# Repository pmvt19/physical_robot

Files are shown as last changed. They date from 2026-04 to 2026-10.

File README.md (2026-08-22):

# SunoBot 

<!-- ![SunoBotLogo](./assets/SunoBotLogo.png) -->

<p align="center">
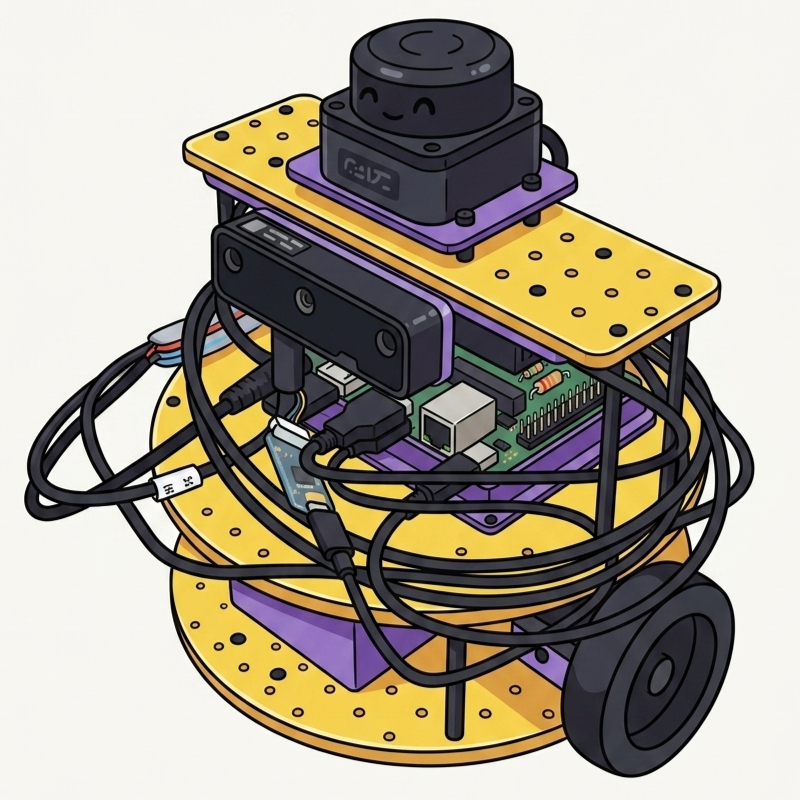
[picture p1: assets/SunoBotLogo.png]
SunoBotLogo


<p align="center">
SunoBot is an open-source autonomous mobile robot platform meant to explore computer vision, motion planning, and robot design.

## Capabilities:

<p float="center">
  
  
  
</p>

# Monitoring UI - RoboMonitor Pro

The RoboMonitor Pro Monitoring UI allows users to monitor the current readings of all on-board sensors on the SunoBot.

The list of natively monitored sensors:
- Lidar
- RGB Camera
- Depth Camera
- Accelerometer
- Gyroscope

The monitoring UI also includes additional information about the real-time motor positions and velocities.

Example:
<p align="center">
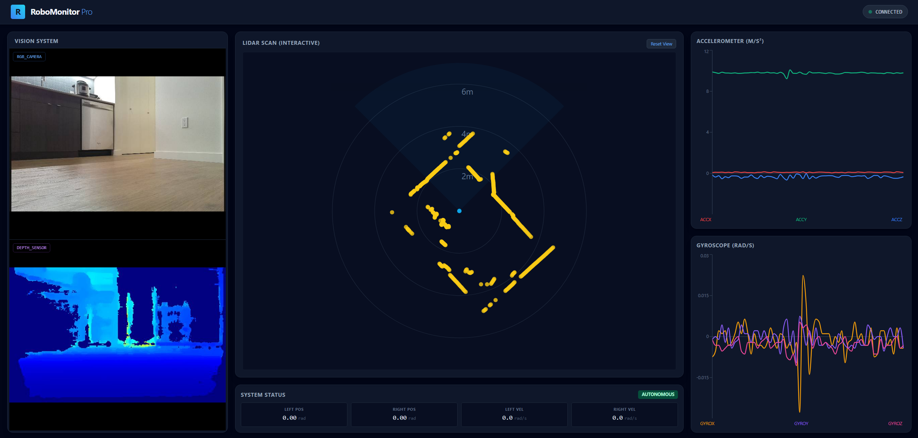
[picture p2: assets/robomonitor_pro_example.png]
RoboMonitorPro

<!-- Insert Example UI Image -->

# Equipped Sensors

## Lidar - RPLidar C1

<p align="center">
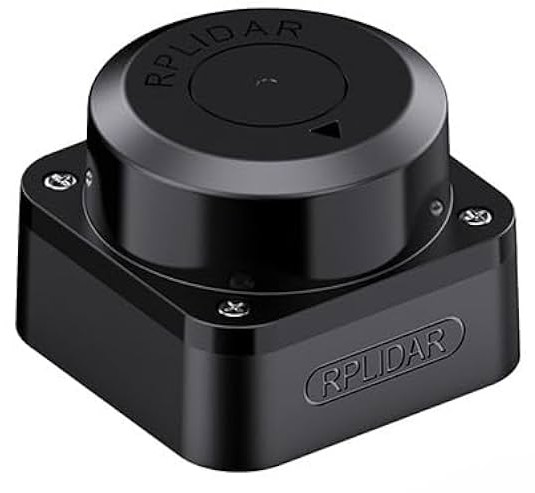
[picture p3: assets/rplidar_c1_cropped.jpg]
RPLidar C1


<!-- Example Readings -->
<!-- Maybe add gif of lidar readings? -->

### Specifications
- Max Range: 12 meters
- Accuracy: 30 mm
- Angular Resolution: 0.72 degrees

## Stereo Depth Camera - Oak-D Lite

<p align="center">
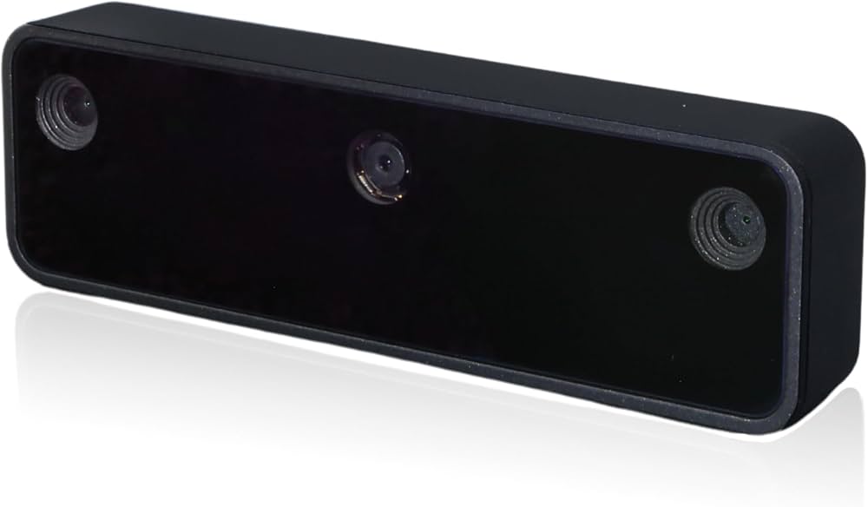
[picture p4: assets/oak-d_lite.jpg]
Oak-D Lite


### Specifications
- Photo Resolution: 13 MP (Auto-Focus Variant)
- Video Resolution: 1080p
- IMU: 6-axis sensor with accelerometer and gyroscope
- Onboard Compute to run computer vision algorithms and models

<!-- Example Readings -->

<!-- Front on Vision, Depth Camera, 3D Point Cloud -->

# Motors - Dynamixel WL430-XL250-T
<p align="center">
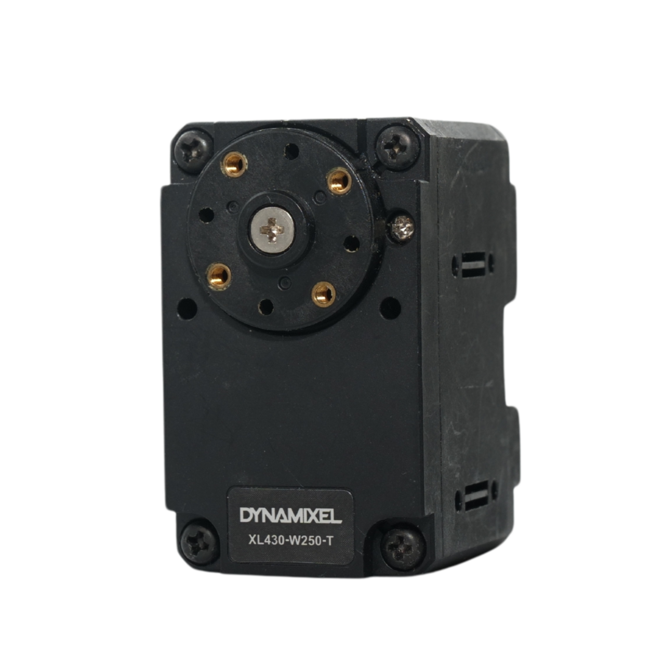
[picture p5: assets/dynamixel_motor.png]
Dynamixel Motors


This motor includes built-in encoders for accurate positioning. 

### Specifications
- Estimated Torque: 0.28 Nm 
- Resolution: 4096 Steps

# Code Installation

Requires Python >=3.12.9

```sh
pip install suno-bot
```

For systems with an Nvidia GPU, you can use the following command to ensure you install torch with cuda to accelerate inference when running local models.

```sh
pip install suno-bot[cuda]
```

# Build List
| Part | Quantity | Unit Price (USD) | Link |
| --- | --- | --- | --- |
| **Compute** | 
| Nvidia Jetson Nano Orin | 1 | $250 | [Amazon](https://a.co/d/08duLBSw) |
| 128 GB Micro SD Card | 1 | $34 | [Amazon](https://a.co/d/0giFn1uy) |
| **Sensors** |
| RPLidar C1 | 1 | $69 | [Amazon](https://a.co/d/01sqCkox) |
| Luxonis OAK-D Camera | 1 | $170 | [Luxonis](https://shop.luxonis.com/products/oak-d-lite-1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) |
| **Motors & Accessories** |
| Dynamixel XL-250 | 2 | $27.50 | [Robotis](https://www.robotis.us/dynamixel-xl430-w250-t/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) |
| U2D2 | 1 | $36.92 | [Robotis](https://www.robotis.us/u2d2/?srsltid=AfmBOooSLo45Nv1YYB132Rkxfk1DpJbxzMnHwRaMWvsoDXhAL2AbefDP) |
| U2D2 Powerboard | 1 | $21.85 | [Robotis](https://www.robotis.us/u2d2-power-hub-board-set/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) | 
| **Power & Accessories** |
| KBT 12V Battery | 1 | $30 | [Amazon](https://a.co/d/07AhwwMU) |
| 8x AA Battery Holder | 1 | $9 | [Amazon](https://a.co/d/021ZlgrT) |
| 20x AA Batteries | 1 | $10 | [Amazon](https://a.co/d/07lIH3iI) |
| USB C to USB A Cable | 1 | $7 | [Amazon](https://a.co/d/0gSawx84) |
| **Assembly Hardware** |
| Turtle Bot 3 Wheel and Tire Kit (2 Pack) | 1 | $10.81 | [Robotis](https://www.robotis.us/tb3-wheel-tire-set-isw-01-2ea/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) |
| Turtle Bot 3 Casters | 2 | $4.03 | [Robotis](https://www.robotis.us/tb3-ball-caster-a01-1ea/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) |
| Screw Pack | 1 | $9 | [Amazon](https://a.co/d/002Dz5YJ) |
| Standoffs | 1 | $10 | [Amazon](https://a.co/d/06RelOfa) |
| **Total** | --- | **$730.64** | --- |

# Chassis & Brackets - 3D Printed Parts
| Part | Quantity | CAD File |
| --- | --- | --- |
| Base Board | 2 | [Link](./CAD/Robot%20Base%20Plate.stl) |
| Motor Mounts | 2 | [Link](./CAD/430T%20Motor%20Mounts.stl) |
| Sensor Mounting Bracket Riser | 1 | [Link](./CAD/Lidar%20Mounting%20Plate%20Wide.stl) |
| Jetson Mount | 1 | [Link](./CAD/Jetson%20Mount.stl) |
| Jetson Securing Bracket | 1 | [Link](./CAD/Jetson%20Securing%20Bracket.stl) |
| Camera Mounting Bracket | 1 | [Link](./CAD/Camera%20Mounting%20Bracket.stl) |
| Camera Mounting Bracket Spacer | 1 | [Link](./CAD/OAK-D%20Lite%20Camera%20Mount.stl) |
| Lidar Mounting Bracket | 1 | [Link](./CAD/Lidar%20Mounting%20Plate.stl) |
| KBT Battery Holder | 1 | [Link](./CAD/KBT%20Battery%20Holder.stl) |
| AA Battery Holder | 1 | [Link](./CAD/8%20AA%20Battery%20Holder%20Horizontal.stl) |

### Printer
Any 3D printer large enough should work to print all of these parts. For reference, I printed these parts using a Prusa MK4S printer with PLA and got fairly decent results.

# Assembly Instructions
Please follow this tutorial for instructions on how to assemble the SunoBot.

# Software Architecture

SunoBot supports three different connection types: Simulated, Server-Client, and Physical (Local).

## Simulated
The simluated robot provides a limited set of functionality primarily used for simple testing.

In simulated mode, the robot only has access to a simulated lidar sensor that requires a prebuilt map to read data from. The only functionalities that work in this case are: SLAM, Global Localization, and Semantic Navigation (given the Semantic Map is already built).

The major limitation here is that you cannot *build* semantic maps since we have not implemented a way to simulate the Stereo Depth camera. However, you can localize, plan, and navigate in a prebuilt semantic map as these actions only require the use of the lidar.

## Running Server-Client
### Software Architecture
<p align="center">
Dynamixel Motors

This version of the robot runs a gRPC Server on the Robot's compute and a client on the off-board computer. The gRPC Server manages reading the live sensor data and acuating the motors based on RPC calls from the client.

This architecture allows the client use the robot client as if it were running locally on the robot instead of connected via a gRPC server-client relationship.

All other functionalities of the robot such as mapping, motion planning, navigation, etc. happens on the client side. This allows the robot to operate with much higher compute power of the off-board machine.

## Running Locally
### Software Architecture
<p align="center">
Dynamixel Motors

This version of the robot has the robot client object read sensor data directly from the Redis server's database. It provides the same functionality as running the robot via server and client, but does not require an internet connection to support the network-based gRPC calls.

It is also possible to run a completely local version of the robot by running both the server and client on the robot. However, this method is not recommended due to the circular network calls that would be made to send data from the robot back to the robot. This implementation does not have zero-copy data transfer. But, in theory, it would work.

# Getting Started Guide

## Setup the config

## Running Locally
*Not fully supported yet*

On the robot computer:
```sh
# Start publishing sensor data
sh physical_robot/scripts/start_sensor_suite.sh
```

## Running via RPC Server-Client

### Running the sensor suite
On the robot computer:
```sh
# Start publishing sensor data
sh physical_robot/scripts/start_sensor_suite.sh

# Start the RPC Server on the robot
python physical_robot/robot/robot_server.py
```

### Using the Monitoring UI

On the Client:
```sh
# Start the Publishing Monitoring Data to Websocket
python physical_robot/ui/ui_server.py

# Run the Javascript App
sh physical_robot/shell_scripts/run_ui.sh
```

# Future Plans
ROS Integration

<!-- # Technology Stack

<p float="center">
  <img src="https://cdn.jsdelivr.net/gh/devicons/devicon/icons/python/python-original.svg" width="22%" style="border-radius: 15px;"/>
  <img src="https://cdn.jsdelivr.net/gh/devicons/devicon/icons/numpy/numpy-original.svg" width="22%" style="border-radius: 15px;"/>
  <img src="https://upload.wikimedia.org/wikipedia/commons/b/b2/SCIPY_2.svg" width=22%" style="border-radius: 15px;"/>
  <img src="https://upload.wikimedia.org/wikipedia/commons/0/05/Scikit_learn_logo_small.svg" width="32%" style="border-radius: 15px;"/>
  <img src="https://huggingface.co/front/assets/huggingface_logo-noborder.svg" width="22%" style="border-radius: 15px;"/>
  <img src="https://www.luxonis.com/assets/marketing/brand/luxonis_logo_symbol.png" width="22%" style="border-radius: 15px;"/>
  <img src="https://www.gstatic.com/lamda/images/gemini_sparkle_v002_d4735304ff6292a690345.svg" width="22%" style="border-radius: 15px;"/>
  <img src="https://cdn.jsdelivr.net/gh/devicons/devicon/icons/opencv/opencv-original.svg" width="22%" style="border-radius: 15px;"/>
  <img src="https://cdn.jsdelivr.net/gh/devicons/devicon/icons/pytorch/pytorch-original.svg" width="22%" style="border-radius: 15px;"/>
  <img src="https://plugins.jetbrains.com/files/14004/1074279/icon/default.png" width="22%" style="border-radius: 15px;"/>
  <img src="https://cdn.jsdelivr.net/gh/devicons/devicon/icons/matplotlib/matplotlib-original.svg" width="22%" style="border-radius: 15px;"/>
  <img src="https://images.icon-icons.com/2415/PNG/512/redis_original_wordmark_logo_icon_146369.png" width="22%" style="border-radius: 15px;"/>
</p> -->

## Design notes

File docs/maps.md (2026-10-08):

# SunoBot Maps

## Map

Raw Map Dimensionality: `(X, Y)`

### World and Grid Coordinates

### Update Map and Localize

### Expandability
As this map is built without knowning the full extent of the environment, it is possible the environment is larger that the initial size of the map. If an update step tries to update a map cell that is outside the bounds of the current size of the map, the map will autoexpand in the X and Y dimensions to at least encompass the cell the new lidar readings were trying to update.

### Inflate Obstacles

A single point on the lidar reading only updates the map obstalces for a single grid cell, which is geometrically where the obstacle is. This is generally fine if our goal was to only map the room geometrically, however motion planning in this map could be quite risky since grid cells close to obstacles are still marked as completely free.

The Inflate Obstacles function expands the occupied cells in the map to create a buffer between the free cells and occupied cells.

<!-- Example Image of Inflated Obstacle Cells -->

## Advanced Map

Raw Map Dimensionality: `(X, Y, 2)`

The Advanced Map stores the count of times each cell was recorded as empty or occupied. Using these counter, we compute a probability that the cell is occupied.

This is a more robust solution as a single reading does not permanently define a cell as occupied. A cell is only considered occupied if it strictly has more occupied readings than unoccupied readings. This means the cell must have a probability of being occupied of more than 50%.
 
$`\text{Occupancy Probablity}_{i,j}`$ = $`\frac{\text{Occupied}_{i,j} + 1}{\text{Occupied}_{i,j} + \text{Unoccupied}_{i,j} + 2}`$ 

### Benefits
This offers greater reliability for objects that may have moved through the scene while mapping, such as a human or pet walking, as these entities will eventually be cleared from the map. 

Additionally, this helps to smooth out noisy lidar readings. Suppose a wall is directly forward and exactly 5 meters away. The lidar may read this distance as 4.7 meters which leaves us with a 30 centimeter error. In the previous map implementation, we would mark the cell corresponding to 4.7 meters forward as occupied and move on, never to be updated or corrected. With the implementation in the advanced map, we will increment the occupied counter of the cell 4.7 meters forward. Since there is not really an object there, as we get more accurate readings from the lidar, it will hopefully show the wall being closer to 5 meters away and we will increment the unoccupied counter for the cell 4.7 meters forward, eventually converging to a occupied probability of 0%.

### Computing Frontiers

Using this method we can compute the boundaries of where the robot has explored.
<!-- Example Image of Frontiers -->

## Semantic Map

Raw Map Dimensionality: Depends on base geometric map (Recommended to use AdvancedMap)

Semantic Map Dimensionality: `(X, Y, 2)`

The Semantic Map adds an additional layer to store information about the semantic information of each obstacle. Semanic information includes what room the obstacle is associated with and what the obstacle is. For example, if the robot registers an oven next to it, it would label the semantic information as (Room: kitchen) & (Object: Oven).

The internal implementation of this map uses either a Map or AdvancedMap to store the geometric representation of the map. It is recommended to use the `AdvancedMap` class for the geometric component of the map, but it is possible to use the `Map` class if required. Just note that the `AdvancedMap` class features will not be available if using the standard `Map` class.

<!-- Example of Raw Semantic Information (Unfloodfilled) -->

### FloodFill Semantics

<!-- Example of Raw Semantic Information (Unfloodfilled) and FloodFilled Map-->

Semantic information is not mapped for every single grid cell in the map. To assign a semantic label to each open grid cell, the semantic map *flood fills* the unlabeled grid cells. For each unlabeled unoccupied grid cell, flood filling assigns the same label as closest labeled grid cell. 

Closest can be measured in 2 ways: BFS or Nearest Neighbors. BFS flood filling respects known obstacles in the map, meaning it finds the shortest collision free path between a labeled and an unlabeled cell. Nearest Neighbor flood filling labels an unlabeled cell with the label of the closest labeled cell using euclidean distance. This means that if a wall is labeled a 'kitchen', then it may label the other side of the wall kitchen as well if that side is open and unlabeled.

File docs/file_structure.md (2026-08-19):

```
physical_robot/
├── physical_robot/
    ├──generated/
        ├──robot_data_pb2_grpc.py...

    ├──saves/
        ├──scenes/
            ├──tmp/
                ├──map/
                ├──map_imgs/
                ├──planner_data/
    ├──maps/
        ├──basic_map.py
        ├──map.py
        ├──advanced_map.py
        ├──abstract_map.py
        ├──semantic_map.py

    ├──shell_scripts/
        ├──proto_gen.sh
        ├──start_lidar_process.sh
        ├──start_camera_process.sh
        ├──start_sensor_suite.sh

    ├──debugging/
        ├──debug.py
        ├──debug_lidar_angles.py

    ├──monitoring/
        ├──viz_camera.py
        ├──viz_robot_lidar.py
        ├──viz_imu.py
        ├──viz_point_cloud.py

    ├──utils/
        ├──utils.py
        ├──test_utils.py

    ├──hardware/
        ├──robot_interface.py (robot_motor_interface.py)
        ├──dxl_controller.py

    ├──sensors/
        ├──physical/
            ├──run_camera.py
            ├──run_camera_elite.py
            ├──run_lidar.py
        ├──simulated/
            ├──simualte_lidar.py
    
    ├──processes/
        ├──run_interactive_robot.py (run_slam.py)
        ├──run_localization_robot.py
        ├──run_robot.py
        ├──run_localize_and_plan.py
        ├──run_nlp_mp_robot.py (TODO)

    ├──machine_learning/ (TODO)
        ├──image_processing/
            ├──image_segmentator.py
        ├──language_processing/
            ├──language_processor.py

    ├──robot/
        ├──robot.py
        ├──robot_space.py
        ├──robot_server.py
        ├──robot_controller.py

    ├──algorithms/
        ├──icp.py
        ├──particle_filter.py

    ├──config/
        ├──config.py

    ├──protos/
        ├──robot_data.proto

    ├──tests/
        ├──test_sensors/
            ├──test_lidar.py
            ├──test_camera.py
            ├──test_imu.py
        ├──test_processes/
            ├──test_particle_filter.py
            ├──test_slam.py??

    ├──tests/
        ├──sensors/
            ├──test_lidar.py
            ├──test_camera.py
            ├──test_imu.py
        ├──processes/
            ├──test_particle_filter.py
            ├──test_slam.py??
            ├──test_vlm_client.py
        ├──visual/
            ├──tbd.py??
        ├──computational/
            ├──test_robot_controller.py
            ├──test_geometry_utils.py
            ├──etc...

    # Potential Future Planning
    ├──mcp/
        ├──server.py
        ├──tools.py
    
    ├──main.py??

Remaining files:
- icp.py
- particle_filter.py

Planned files:
- image_segmentator.py
- language_processor.py
- run_nlp_mp_robot.py
- start_sensor_suite.sh
- start_camera_process.sh
- semantic_map.py
- run_slam_semantic_mapping.py

Files to Rename:
- run_interactive_robot.py -> run_slam.py
- run_localization_robot.py -> run_global_localization.py
- run_localize_and_plan.py -> run_motion_planning.py??

- run_camera.py -> run_oakd_lite.py or run_oakd_camera.py

│   ├── components/
│   │   ├── Button.js
│   │   └── Header.js
│   ├── pages/
│   │   ├── HomePage.js
│   │   └── AboutPage.js
│   └── App.js
├── public/
│   ├── index.html
│   └── favicon.ico
├── package.json
└── README.md
```

## Installation

```sh
conda create --name <name> python=3.10.18

sh env_setup.sh
```

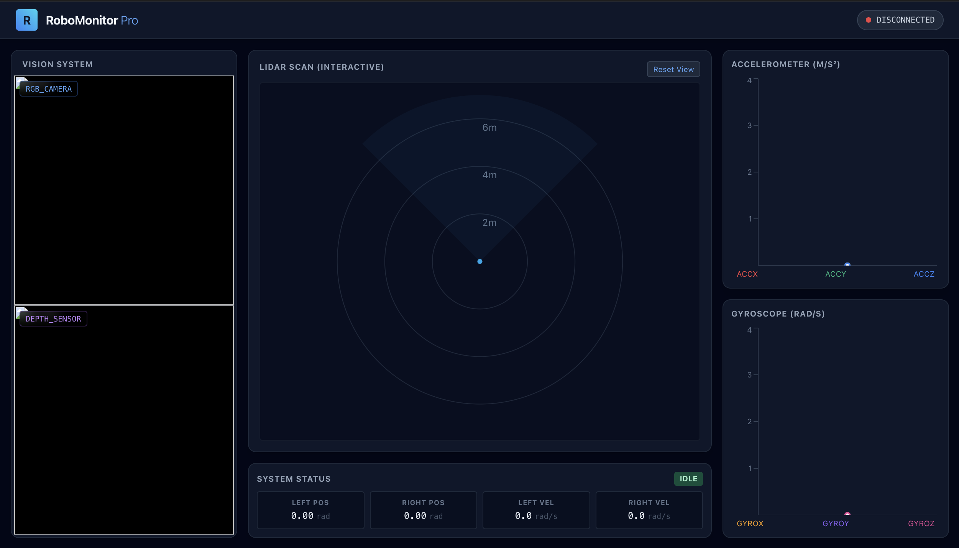
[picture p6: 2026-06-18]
assets/robomonitor_pro_blank.png

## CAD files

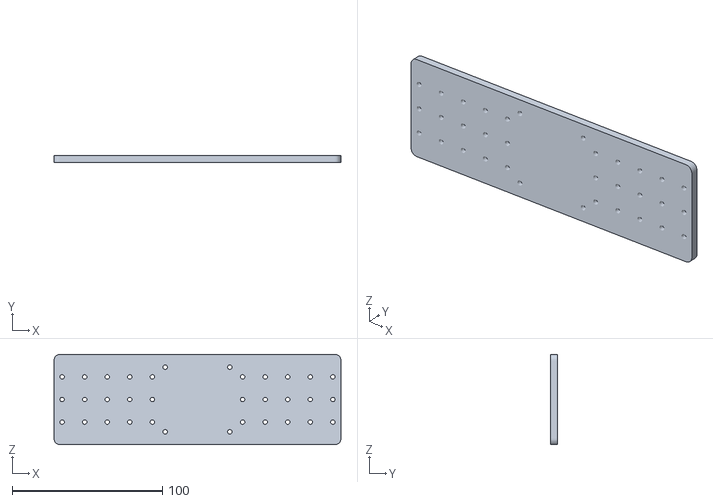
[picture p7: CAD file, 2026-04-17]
CAD/Lidar Mounting Plate Wide.stl
190.8 x 4.50 x 60.0

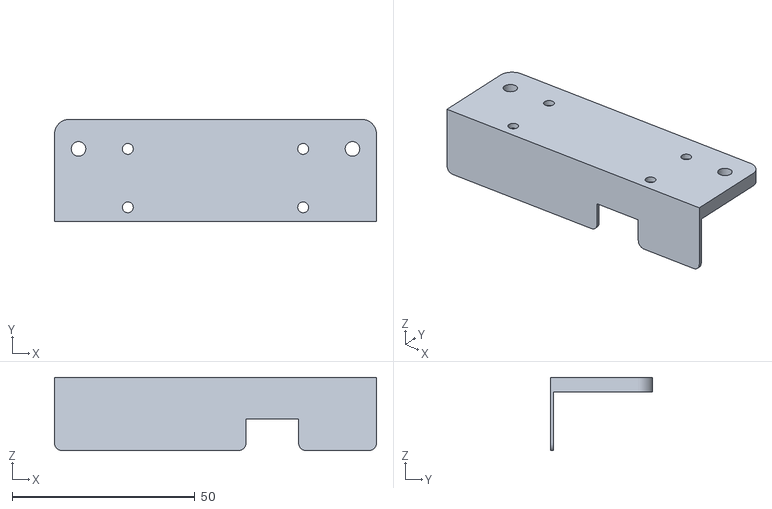
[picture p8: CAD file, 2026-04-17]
CAD/OAK-D Lite Camera Mount.stl
88.2 x 28.0 x 20.0

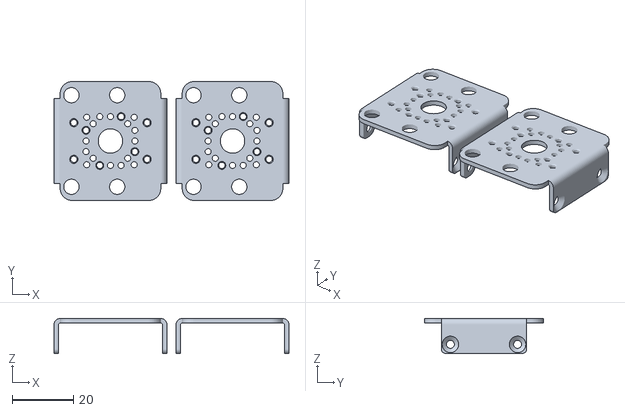
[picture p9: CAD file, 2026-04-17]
CAD/430T Motor Mounts.stl
77.0 x 39.0 x 11.5

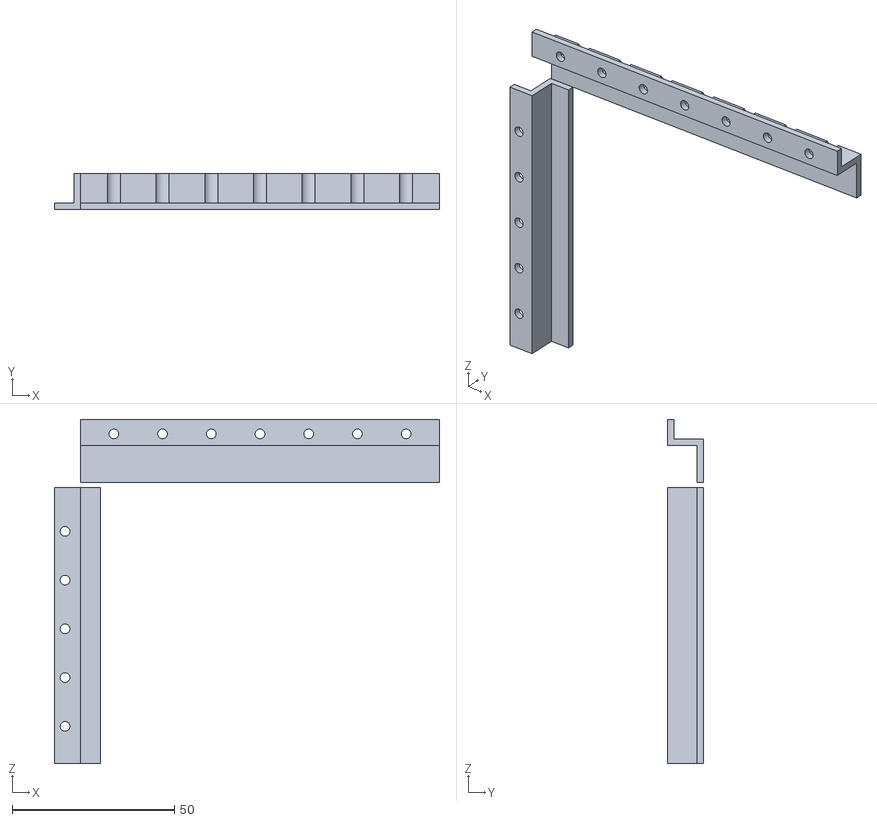
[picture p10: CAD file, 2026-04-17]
CAD/Jetson Securing Bracket.stl
118.5 x 11.0 x 106.0

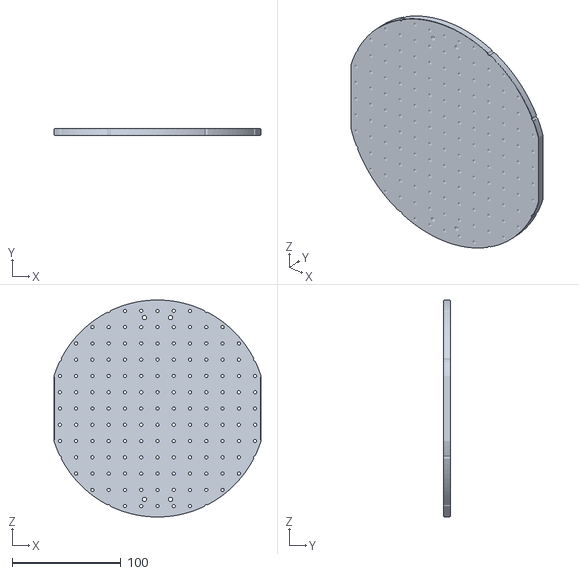
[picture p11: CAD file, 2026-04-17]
CAD/Robot Base Plate.stl
190.8 x 6.00 x 200.0

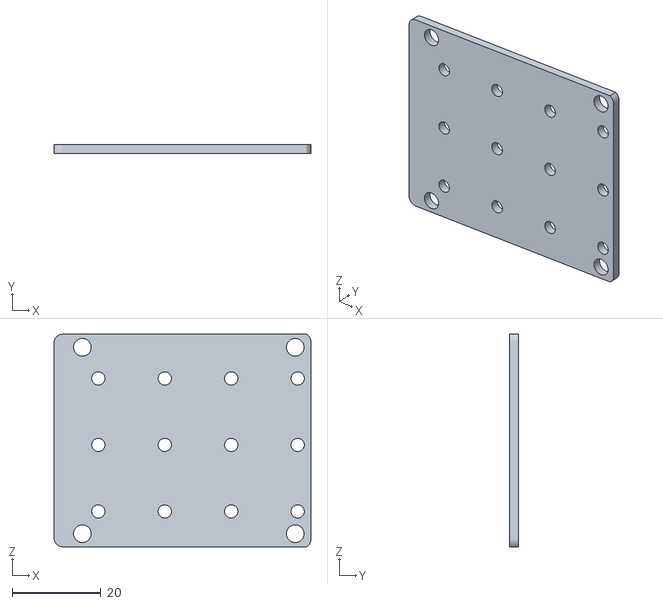
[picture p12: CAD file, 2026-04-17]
CAD/U2D2 Powerboard Mounting Bracket.stl
58.0 x 2.00 x 48.0

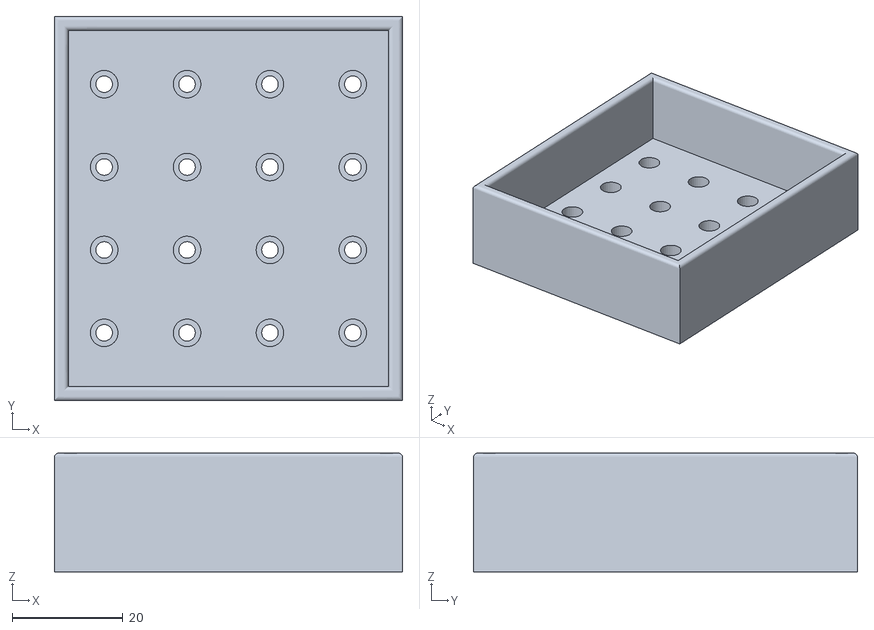
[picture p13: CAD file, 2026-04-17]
CAD/8 AA Battery Holder Horizontal.stl
63.0 x 69.5 x 21.5

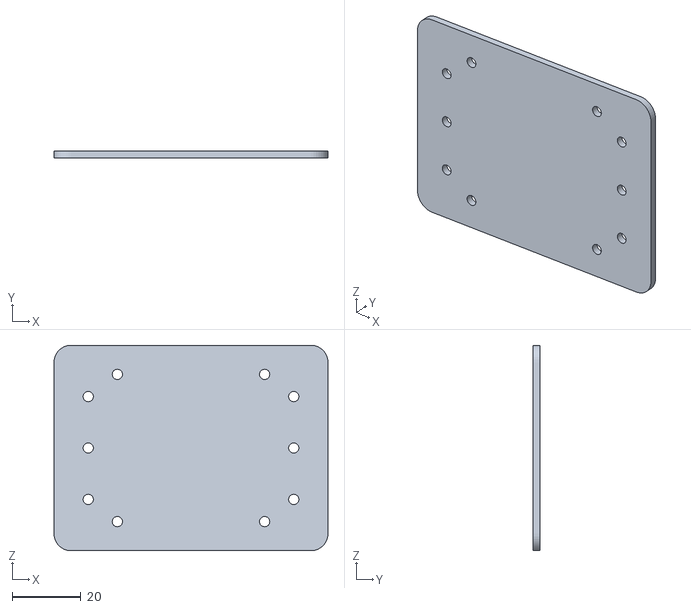
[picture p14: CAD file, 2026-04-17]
CAD/Lidar Mounting Plate.stl
80.0 x 2.00 x 60.0

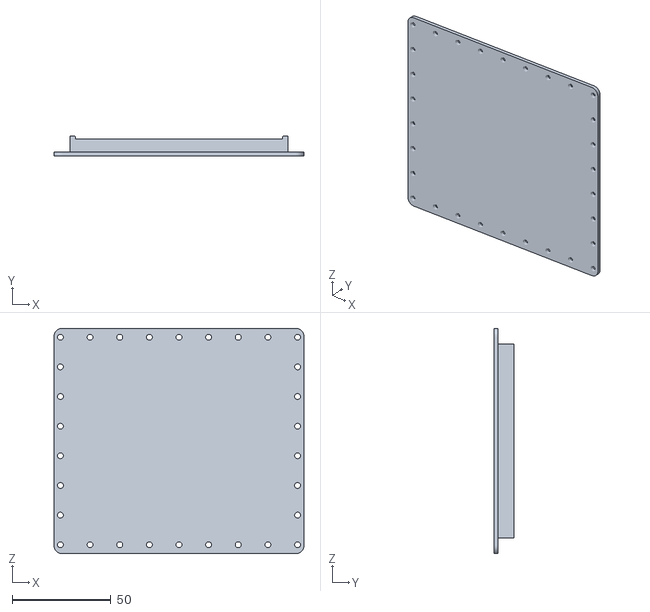
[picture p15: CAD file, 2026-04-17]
CAD/Jetson Mount.stl
126.5 x 10.0 x 114.0

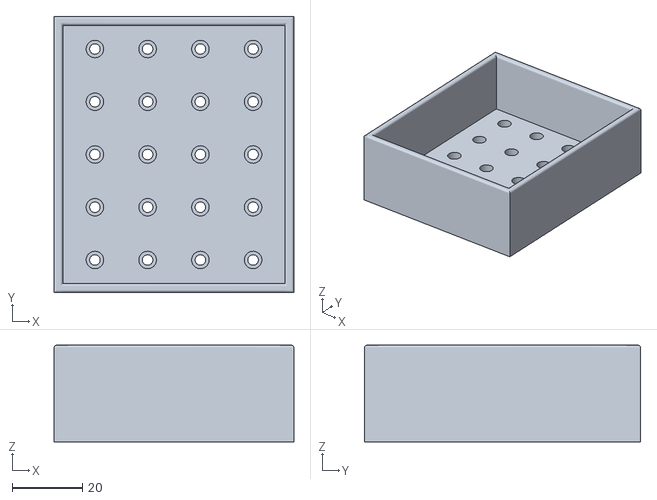
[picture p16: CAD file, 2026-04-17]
CAD/KBT Battery Holder.stl
68.2 x 78.5 x 27.5

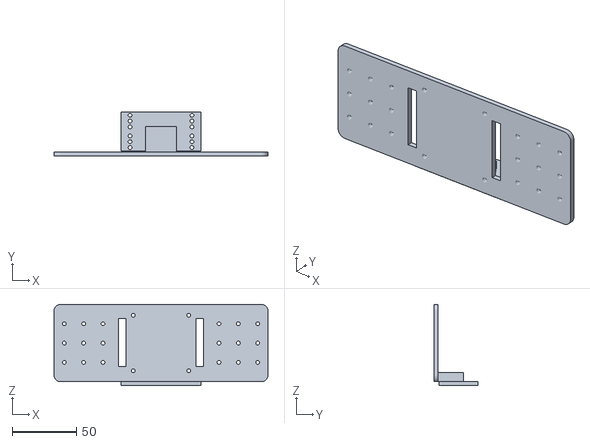
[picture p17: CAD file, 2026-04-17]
CAD/Camera Mounting Bracket.stl
166.0 x 34.0 x 63.0

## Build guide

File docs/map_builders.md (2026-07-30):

# MapBuilders

The `MapBuilder` classes provide an easy to use interface for building maps of an environment. The SunoBot code provides 3 variants of MapBuilders: `MapBuilder`, `AdvancedMapBuilder`, and `SemanticMapBuilder` classes. Intuitively, these variants build a `Map`, `AdvancedMap`, or `SemanticMap` respectively.

# MapBuilder Class

The `MapBuilder` class coordinates a robotic system and its LiDAR sensor data to construct, update, and track a spatial map over time. It maintains the robot's current state, trajectories, and handles map updates per time step.

## Table of Contents
- [Initialization](#initialization)
- [Methods](#methods)
- [Usage Example](#usage-example)

---

## Initialization

```python
def __init__(self, robot, map_resolution=10.0, manual_lidar_verification=False)
```

Initializes the map building coordinator.

### Parameters
| Parameter | Type | Default | Description |
| :--- | :--- | :--- | :--- |
| `robot` | `Robot` | *Required* | An instance of the `Robot` class providing movement and sensor interfaces. |
| `map_resolution` | `float` | `10.0` | The grid resolution scale for the generated map. Units in millimeters. |
| `manual_lidar_verification` | `bool` | `False` | If `True`, prompts manual user verification for every LiDAR reading. Mainly used for debugging purposes. |

### Internal State Attributes
* **`self.robot_state`** (`np.ndarray`): A 3-element array `[x, y, theta]` tracking the robot's current pose. Starts at `[0.0, 0.0, 0.0]`.
* **`self.map`** (`Map`): The underlying map object initialized with the given resolution.
* **`self.robot_trajectory`** (`list[np.ndarray]`): A history list recording the robot's state at every step.

---

## Methods

### `init()`
Performs the initial LiDAR scan to establish and initialize the map's baseline geometry.
* **Returns:** `None`

### `step(m)`
Executes a single iteration of the localization and mapping loop. It predicts the new state based on movement, reads the sensor, and refines the map.
* **Parameters:** `m`: Movement/Odometry data passed to the robot's state prediction model.
* **Returns:** `None`

### `get_map()`
* **Returns:** `Map` — The current state of the map object.

### `get_robot_state()`
* **Returns:** `np.ndarray` — The current `[x, y, theta]` pose of the robot.

### `get_robot_trajectory()`
* **Returns:** `list[np.ndarray]` — A chronological list of all historic robot states.

### `show()`
Renders a visual representation of the current map using `matplotlib`.
* **Returns:** `None`

---

## Usage Example

```python
from physical_robot.robot import Robot
from physical_robot.map_builder import MapBuilder

# 1. Setup the robot and builder
robot = Robot()
map_builder = MapBuilder(robot=robot, map_resolution=12.5)

# 2. Baseline the map
map_builder.init()

while True:
    # 3. Get Motion Commands from User
    motion_command = robot.request_motion_command_from_user()
    if motion_command[0] == '': # No Motion Command
        break

    # 4. Move the Robot
    m = robot.command_motion(motion_command)

    # 5. Step The Map Builder
    map_builder.step(m)

    # 6. Fetch results or visualize
    current_pose = map_builder.get_robot_state()
    print(f"Robot is at: {current_pose}")

    # 7. Visualize Current Map
    map_builder.show()

# 8. Save the Map
map_builder.get_map().save(map_save_dir="saves/maps")
```

## AdvancedMapBuilder

`AdvancedMapBuilder` inherits from `MapBuilder` and preserves the same high-level map-building workflow while using an `AdvancedMap` implementation for richer geometry and exploration features.

### Key differences from `MapBuilder`
- Inherits all public methods from `MapBuilder`: `init()`, `step(m)`, `get_map()`, `get_robot_state()`, `get_robot_trajectory()`, and `show()`.
- Replaces the base `Map` with `AdvancedMap` during initialization.
- Gains advanced map semantics such as probabilistic occupancy, obstacle inflation, and frontier candidate generation.
- Uses the same LiDAR-based scan initialization and update loop as `MapBuilder`.

### Initialization
```python
map_builder = AdvancedMapBuilder(robot=robot, map_resolution=12.5)
```
This constructs a map builder whose underlying map is an `AdvancedMap`.

### Behavior
- `init()` performs the initial LiDAR scan and initializes the advanced map.
- `step(m)` predicts the robot state, reads an updated LiDAR scan, runs ICP alignment, updates the `AdvancedMap`, and appends the new pose to the robot trajectory.
- `get_map()` returns the `AdvancedMap` instance, enabling access to advanced operations such as inflated occupancy and frontier detection.

### When to use
Use `AdvancedMapBuilder` when you need more than a simple occupancy map and want a map representation that supports:
- better alignment between scans and map geometry,
- probabilistic occupancy values,
- obstacle inflation for planning,
- frontier candidate extraction for exploration.

## SemanticMapBuilder
The `SemanticMapBuilder` extends `MapBuilder` to produce a `SemanticMap` that combines geometric mapping with semantic labels (rooms and objects).

### Purpose
The `SemanticMapBuilder` augments an occupancy/geometry map with semantic information derived from RGB images and point clouds. It is intended for use-cases where high-level scene understanding (room types, object labels) improves exploration, planning, or human-facing visualization.

### Key Features
- Builds a `SemanticMap` (backed by an `AdvancedMap`) that stores both geometry and semantic layers (e.g., `room`, `object`).
- Integrates LiDAR, RGB camera, and point-cloud data to localize, segment, and label the environment.
- Uses an image segmenter and a vision-language model (VLM) client to assign room labels and object semantics.

### Sensor & ML Dependencies
- LiDAR: used for geometry updates and scan-to-map alignment (via the same LiDAR-based flow as `MapBuilder`/`AdvancedMapBuilder`).
- RGB Camera: provides images for segmentation and room-label queries.
- Point Cloud: combined with image segmentation to label 3D points with semantic categories.
- Image segmentation: `physical_robot.models.segmentation.image_segmentation.ImageSegmenter` is used to produce pixel-level segments.
- Vision-Language Model (VLM): `physical_robot.models.vlm.vlm_client.VLMClient` is queried (with prompts such as `ASSIGN_ROOM_LABEL`) to produce a room-level label for the current view.

Files: see [physical_robot/map_builder/semantic_map_builder.py](physical_robot/map_builder/semantic_map_builder.py) for the implementation and references to:
- [physical_robot/maps/semantic_map.py](physical_robot/maps/semantic_map.py)
- [physical_robot/models/segmentation/image_segmentation.py](physical_robot/models/segmentation/image_segmentation.py)
- [physical_robot/models/vlm/vlm_client.py](physical_robot/models/vlm/vlm_client.py)

### Workflow (what `step(m)` does)
1. Update the internal robot state using the provided motion/odometry `m`.
2. Read an updated LiDAR scan (optionally with manual verification).
3. Capture an RGB image from the robot camera.
4. Read the point cloud snapshot.
5. Query the VLM with the RGB image and a prompt that lists known/invalid rooms to get a room label.
6. Run image segmentation on the RGB image to get pixel-level segments and labels.
7. Project/associate segmentation labels onto the point cloud and filter/format points for the semantic map.
8. Update the `SemanticMap` with both geometry (from LiDAR / point cloud) and semantics (room/object labels), and append the robot pose to the trajectory.

This workflow is implemented in `SemanticMapBuilder.step()` and tightly couples geometric updates with semantic inference so the map remains both spatially accurate and semantically meaningful.

### Visualization (`show()`)
`SemanticMapBuilder.show()` renders multiple panels using `matplotlib`:
- A geometric/occupancy view of the map.
- A semantic layer for `room` labels.
- A semantic layer for `object` labels.

### Initialization
```python
from physical_robot.robot import Robot
from physical_robot.map_builder import SemanticMapBuilder

robot = Robot()
builder = SemanticMapBuilder(robot=robot, map_resolution=10.0, manual_lidar_verification=False)
builder.init()
```

### When to use
- Use `SemanticMapBuilder` when downstream tasks (navigation, human-robot interaction, semantic exploration) require knowledge of room types or object categories beyond raw geometry.

### Notes and configuration
- The builder instantiates `ImageSegmenter` and `VLMClient` by default; these components may require model weights, credentials, or network access depending on your configured backends. Check their module-level docs for setup details.
- The `map_resolution` parameter controls the underlying `AdvancedMap` resolution; pick a resolution appropriate for your sensors and environment scale.
- For debugging or mapping quality control, enable `manual_lidar_verification` to pause for manual LiDAR checks during `step()`.

For implementation details, see the source: [physical_robot/map_builder/semantic_map_builder.py](physical_robot/map_builder/semantic_map_builder.py).

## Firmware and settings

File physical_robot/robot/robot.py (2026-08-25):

import time
import copy
import redis
import rerun as rr
import numpy as np
import matplotlib.pyplot as plt
import logging
import threading
# import open3d as o3d

import grpc
import physical_robot.generated.robot_data_pb2 as pb2
import physical_robot.generated.robot_data_pb2_grpc as pb2_grpc

from shapely import Point, Polygon, affinity

from physical_robot.config import config
from physical_robot.hardware.motors.dxl_controller import DynamixelController, TORQUE_ENABLE, TORQUE_DISABLE
from physical_robot.hardware.motors.robot_motor_interface import RobotInterface
from physical_robot.hardware.sensors.simulated.simulate_lidar import SimulatedLidar
from physical_robot.utils import create_rectangle_geometry, point_segment_distance, point_to_points_distance, register_logger, pairwise_dists
from .robot_controller import RobotController

logger = register_logger(logger_name=__name__, log_filename='robot', level=logging.INFO, std_err=False)

class Robot():
    def __init__(self, connection='simulated'):
        self.connection = connection
        
        # TODO: Do some design work and see if this is necessary, I'm leaning to not having this, (It's not used internally)
        # TODO: This might be used internally if lidar is simulated as well so might be worth it to keep

        # Initialize Current State (Starts at [x=0.0, y=0.0, theta=0.0])
        self.state = np.array([0.0, 0.0, 0.0])

        # Robot Specific Variables:
        # self.r -> move to Robot as self.wheel_radius
        # self.L -> move to Robot as self.wheelbase_length

        self.wheel_radius = (66.5/2)
        self.wheel_circumference = 2 * self.wheel_radius * np.pi
        self.wheelbase_length = 210
        self.robot_radius = self.wheelbase_length / 2

        self.guard_active_motion = False

        # TODO: Remove after successful rollout (Use self.wheel_radius and self.wheelbase_length)
        self.r = self.wheel_radius
        self.L = self.wheelbase_length

        # Thresholds
        self.active_distance_threshold = 300
        self.local_planner_distance_threshold = 400

        self.motion_controller = RobotController()

        # If Robot is not required to be tied to the physical robot, don't initialize the controllers
        if self.connection == 'simulated':
            self.const_reference_map_for_lidar = None
            self.simulated_lidar = SimulatedLidar(self.const_reference_map_for_lidar, angular_resolution=360, max_dist=12000) # TODO: Check units for max_dist
        elif self.connection == 'client':
            # TODO: Clean After Successful Release
            # channel = grpc.insecure_channel('192.168.12.155:50051')

            # Define the maximum receive message length (e.g., 10 MB)
            MAX_RECEIVE_MESSAGE_LENGTH = 10 * 1024 * 1024  # 10 MB

            # Create a gRPC channel with the increased message size limit
            options = [('grpc.max_receive_message_length', MAX_RECEIVE_MESSAGE_LENGTH)]
            channel = grpc.insecure_channel(config['client']['channel_address'], options=options)
            self.stub = pb2_grpc.RobotServerStub(channel)
            print("Motor Logs will appear in the machine where the Robot Server is run")
        elif self.connection == 'physical':
            # Initialize Classes For Motor Control

            # TODO: Clean After Successful Release
            # self.controller = DynamixelController(device_name=device_name, motor_ids=[1, 2])
            # self.ri = RobotInterface(controller=self.controller)

            self.controller = DynamixelController(device_name=config['physical']['dxl_motor_port'], motor_ids=[1, 2])
            self.ri = RobotInterface(controller=self.controller)
            self.ri.set_profile_velocity()

            # Connect to Redis Server for Publishing Lidar Data
            # self.redis_client = redis.Redis(host='localhost', port=6379, db=0)

            self.redis_client = redis.Redis(host=config['physical']['redis_host'], port=config['physical']['redis_port'], db=0)
        else:
            raise NotImplementedError

    def run_keyboard_control(self):
        """
        See if we can run keyboard control from here if the robot is not simulated
        """
        pass

    ### ------- Reading Sensors ------- ###
    
    def _get_single_lidar_reading(self, wait_for_updated_reading):
        if self.connection == 'simulated':
            # DO SOMETHING
            raise NotImplementedError
        else:
            if self.connection == 'client':
                # Make RPC Call here 
                request_ack = pb2.Acknowledge(
                    success=True,
                    message="Client is ready for data!"
                )
                lidar_data = self.stub.GetLatestLidarData(request_ack)

                init_time = lidar_data.timestamp # Move to inside if?
                if wait_for_updated_reading:
                    cur_time = init_time
                    while init_time == cur_time: # TODO: Use is_close?
                        lidar_data = self.stub.GetLatestLidarData(request_ack)
                        cur_time = lidar_data.timestamp
                
                angles = np.array(lidar_data.angles)
                dist = np.array(lidar_data.dists)
                print("Came at time: ", lidar_data.timestamp)
                lidar_data = np.stack((angles, dist), axis=1)

            elif self.connection == 'physical':
                init_time = float(self.redis_client.get('time')) # Move to inside if?
                lidar_data = np.frombuffer(self.redis_client.get("lidar_data")).reshape(-1, 2)
                
                if wait_for_updated_reading:
                    cur_time = init_time
                    while init_time == cur_time: # TODO: Use is_close?
                        cur_time = float(self.redis_client.get('time'))
                        print("Waiting for updated lidar")
                    lidar_data = np.frombuffer(self.redis_client.get("lidar_data")).reshape(-1, 2)

                angles = lidar_data[:, 0]
                dist = lidar_data[:, 1]
            
            # Filter Noisy Lidar Points Close to Robot
            threshold = 90 # Units mm
            good_lidar_points_mask = lidar_data[:, 1] > threshold
            lidar_data = lidar_data[good_lidar_points_mask]

            # Fix Raw Lidar Output Format
            lidar_data[:, 0] = 360 - lidar_data[:, 0] # Make angles direction CCW
            lidar_data[:, 0] = np.deg2rad(lidar_data[:, 0]) # Convert Degrees to Radians

            angles = lidar_data[:, 0]
            dist = lidar_data[:, 1]

            cos = np.cos(angles)
            sin = np.sin(angles)

            x_coords = dist * cos
            y_coords = dist * sin
            z_coords = np.ones_like(x_coords)

            coords = np.stack((x_coords, y_coords, z_coords), axis=1)
            return coords, lidar_data, init_time

    def read_lidar_updated(self, manual_verification=False, wait_for_updated_reading=False, auto_retry_threshold=400):
        # coords, lidar_data = self._get_single_lidar_reading(wait_for_updated_reading)
        # if manual_verification:
        #     plt.scatter(coords[:, 0], coords[:, 1])
        #     plt.show()
        #     user_input = input("Do you want to reread the lidar?")
        #     while user_input == 'yes':
        #         coords, lidar_data = self._get_single_lidar_reading(wait_for_updated_reading)
        #         plt.scatter(coords[:, 0], coords[:, 1])
        #         plt.show()
        #         user_input = input("Do you want to reread the lidar?")
        # return coords, lidar_data

        user_input = 'yes'
        while user_input == 'yes':
            coords, lidar_data, _ = self._get_single_lidar_reading(wait_for_updated_reading)

            # Auto-Retry Logic
            if len(lidar_data) < auto_retry_threshold:
                print("Auto Retry Triggered")
                continue

            if manual_verification:
                plt.scatter(coords[:, 0], coords[:, 1])
                plt.show()
                user_input = input("Do you want to reread the lidar?")
            else:
                break
        return coords, lidar_data
    
    def read_rgb_camera(self):
        if self.connection == 'simulated':
            raise NotImplementedError
        elif self.connection == 'client':
            # Make RPC Call here 
            request_ack = pb2.Acknowledge(
                success=True,
                message="Client is ready for data!"
            )

            camera_data = self.stub.GetLatestImageData(request_ack)
            rgb_img = np.frombuffer(camera_data.rgb_img.img_bytes, dtype=camera_data.rgb_img.type).reshape(*camera_data.rgb_img.shape)
            depth_img = np.frombuffer(camera_data.depth_img.img_bytes, dtype=camera_data.depth_img.type).reshape(*camera_data.depth_img.shape)
            return rgb_img, depth_img
        else:
            raise NotImplementedError

    def read_depth_camera(self):
        if self.connection == 'simulated':
            raise NotImplementedError
        elif self.connection == 'client':
            # Make RPC Call here 
            request_ack = pb2.Acknowledge(
                success=True,
                message="Client is ready for data!"
            )
            
            camera_data = self.stub.GetLatestImageData(request_ack)
            depth_img_proto = camera_data.depth_img
            depth_img = np.frombuffer(depth_img_proto.img_bytes, dtype=depth_img_proto.type).reshape(*depth_img_proto.shape)
            return depth_img
        else:
            raise NotImplementedError
        
    def read_point_cloud(self, filter=True):
        if self.connection == 'simulated':
            raise NotImplementedError
        elif self.connection == 'client':
            # Make RPC Call here 
            request_ack = pb2.Acknowledge(
                success=True,
                message="Client is ready for data!"
            )

            oakd_lite_data = self.stub.GetLatestOakdLiteData(request_ack)

            point_cloud_data_proto = oakd_lite_data.point_cloud_data

            point_cloud_coords = np.frombuffer(point_cloud_data_proto.point_cloud_coords.img_bytes, dtype=point_cloud_data_proto.point_cloud_coords.type).reshape(*point_cloud_data_proto.point_cloud_coords.shape)
            point_cloud_colors = np.frombuffer(point_cloud_data_proto.point_cloud_colors.img_bytes, dtype=point_cloud_data_proto.point_cloud_colors.type).reshape(*point_cloud_data_proto.point_cloud_colors.shape)

            ## -- Filtering -- ##
            # if filter:
            #     pcd = o3d.geometry.PointCloud()
            #     pcd.points = o3d.utility.Vector3dVector(point_cloud_coords)
            #     pcd.colors = o3d.utility.Vector3dVector(point_cloud_colors[:, :3])

            #     voxel_down_pcd = pcd.voxel_down_sample(voxel_size=0.2)
            #     return np.asarray(voxel_down_pcd.points), np.asarray(voxel_down_pcd.colors)[:, ::-1]
            ## -- Filtering -- ##

            return point_cloud_coords, point_cloud_colors
        else:
            raise NotImplementedError

    def read_imu(self):
        if self.connection == 'simulated':
            raise NotImplementedError
        elif self.connection == 'client':

            request_ack = pb2.Acknowledge(
                success=True,
                message="Client is ready for data!"
            )
            imu_data = self.stub.GetLatestIMUData(request_ack, timeout=2)

            accel_data = [imu_data.accel_x, imu_data.accel_y, imu_data.accel_z]
            gyro_data = [imu_data.gyro_x, imu_data.gyro_y, imu_data.gyro_z]

            return accel_data, gyro_data
            
        elif self.connection == 'physical':
            raise NotImplementedError
        
    def read_motor_positions(self):
        if self.connection == 'simulated':
            raise NotImplementedError
        elif self.connection == 'client':
            request_ack = pb2.Acknowledge(
                success=True,
                message="Client is ready for data!"
            )
            robot_motor_positions = self.stub.GetMotorPositions(request_ack, timeout=2)
            return np.array([robot_motor_positions.motor_position_left, robot_motor_positions.motor_position_right])
            
        elif self.connection == 'physical':
            raise NotImplementedError
    
    def read_motor_velocities(self):
        if self.connection == 'simulated':
            raise NotImplementedError
        elif self.connection == 'client':
            request_ack = pb2.Acknowledge(
                success=True,
                message="Client is ready for data!"
            )
            robot_motor_velocites = self.stub.GetMotorVelocities(request_ack, timeout=2)
            return np.array([robot_motor_velocites.motor_velocity_left, robot_motor_velocites.motor_velocity_right])
            
        elif self.connection == 'physical':
            raise NotImplementedError
        
    ### ------- Reading Sensors ------- ###
    
    def motion_command_to_pseudo_motor_diffs(self, motion_command):
        motion_type, pseudo_avg_motion = motion_command

        # Pseudo Motor Diff Examples:
        # [100.0, -100.0], # Forward 100.0 mm relative to heading 
        # [-np.pi/2, -np.pi/2], # Turn in place pi/2 radians CW TODO: CHECK DIRECTION

        if motion_type == 'linear':
            m = np.array([pseudo_avg_motion, -pseudo_avg_motion])
        elif motion_type == 'angular':
            m = np.array([pseudo_avg_motion, pseudo_avg_motion]) # TODO: Check if these need to be negated
        else:
            print("NEED TO RAISE BETTER EXCEPTION")
            raise NotImplementedError
        return m
    
    def predict_state(self, state, motor_position_differential):
        signs = np.sign(motor_position_differential)

        """
        Don't need to break down like this?

        Return: What should we return??
        """

        
        abs_motion = np.abs(motor_position_differential)
        if signs[0] == -1 and signs[1] == -1:
            # Turn In-Place Left
            avg_motion = np.mean(abs_motion)
            motion_type = 'angular'
        elif signs[0] == 1 and signs[1] == 1:
            # Turn In-Place Right
            avg_motion = -1 * np.mean(abs_motion)
            motion_type = 'angular'
        elif signs[0] == 1 and signs[1] == -1:
            # Forward
            avg_motion = np.mean(abs_motion)
            motion_type = 'linear'
        elif signs[0] == -1 and signs[1] == 1:
            # Backward?
            avg_motion = -1 * np.mean(abs_motion)
            motion_type = 'linear'
        else:
            print("Ensure the U2D2 PowerBoard is On")
            raise NotImplementedError

        x, y, theta = state

        if motion_type == 'linear':
            direction_vector = np.array([np.cos(theta), np.sin(theta), 0.0])
            dx_state = direction_vector * avg_motion
            predicted_state = state + dx_state

        elif motion_type == 'angular':
            dx_state = np.array([0.0, 0.0, avg_motion])
            predicted_state = state + dx_state
        else:
            raise NotImplementedError

        return predicted_state

    def command_motion_and_predict_state(self, state, motion_command):
        m = self.command_motion_trial(motion_command)
        predicted_state = self.predict_state(state, m)
        return m, predicted_state
    
    def request_motion_command_from_user(self):
        """
        Returns: [status, motion_type, angular]
        """
        while True:
            command = input("Enter Robot Motion Command or type \"quit\":\n")

            if command == "quit":
                return ['', 0.0]

            try:
                # TODO: More useful exception messages here
                motion_type, dist = command.split(",")
                dist = float(dist)
                assert(motion_type == 'linear' or motion_type == 'angular')

                return [motion_type, dist]
            except:
                print("That was not a valid command, please try again!")
        
    def get_relative_transformation(self, motor_differentials):
        pass

    ### --- Motion Monitoring --- ###
    def local_planner(self, motion_command):
        motion_type, dist = motion_command
        if motion_type == 'linear':
            coords, raw_lidar_data = self.read_lidar_updated(wait_for_updated_reading=True) # Coords: (M, 3), Raw Lidar Data: (M, 2)

            cur_state = np.array([0.0, 0.0, 0.0]) # Current State (Local Frame)
            desired_state = np.array([dist, 0.0, 0.0]) # Desired State (Local Frame)

            # Filter Out Coords Near Robot
            p2p_dists = point_to_points_distance(cur_state[:2], coords[:, :2]).flatten()
            print(p2p_dists.shape)
            coords = coords[p2p_dists > self.local_planner_distance_threshold]

            line_segment = np.array([[0.0, 0.0, dist, 0.0]])
            dists = point_segment_distance(line_segment, coords[:, :2]) # (1, M)
            dists = dists.flatten()

            collision_coords_mask = dists < self.local_planner_distance_threshold

            if np.sum(collision_coords_mask) > 0:
                collision_coords = coords[collision_coords_mask]

                coord_dist_to_start = np.linalg.norm(collision_coords, axis=1)
                problem_coord = collision_coords[np.argmin(coord_dist_to_start)]

                problem_coord = problem_coord[:2]

                a = 1
                b = -2 * problem_coord[0]
                c = (problem_coord[0]**2 + problem_coord[1]**2 - self.local_planner_distance_threshold**2)
                
                sol1 = (-b + np.sqrt(b**2 - 4*a*c)) / 2
                sol2 = (-b - np.sqrt(b**2 - 4*a*c)) / 2

                dist_candidates = np.array([sol1, sol2])
                dist_idx = np.argmin(np.abs(dist_candidates))

                return ['linear', dist_candidates[dist_idx]]
                
        return motion_command
    
    def active_lidar_monitoring(self, pause_motion, thread_stop):

        while not thread_stop.is_set():
            _, raw_lidar_data = self.read_lidar_updated(wait_for_updated_reading=False)
            dists = raw_lidar_data[:, 1]
            min_dist = np.min(dists)

            if min_dist < self.active_distance_threshold:
                pause_motion.set()
            else:
                pause_motion.clear()

    def advanced_active_lidar_monitoring(self, pause_motion, thread_stop, desired_motor_pos_1, desired_motor_pos_2):
        
        while not thread_stop.is_set():
            current_motor_pos_1, current_motor_pos_2 = self.ri.get_motor_positions()

            pulse_diff_motor_1 = desired_motor_pos_1 - current_motor_pos_1
            revs_till_goal = pulse_diff_motor_1 / self.ri.pulse_per_rev
            dist_to_goal = revs_till_goal * self.wheel_circumference

            line_segment = np.array([[0.0, 0.0, dist_to_goal, 0.0]])
            coords, raw_lidar_data = self.read_lidar_updated(wait_for_updated_reading=False)

            # TODO: Filter Out Starting Points

            # Filter Out Coords Near Robot
            p2p_dists = point_to_points_distance(np.array([0.0, 0.0]), coords[:, :2]).flatten()
            coords = coords[p2p_dists > self.active_distance_threshold]

            dists = point_segment_distance(line_segment, coords[:, :2]) # (1, M)
            dists = dists.flatten()

            collision_coords_mask = dists < self.active_distance_threshold

            if np.sum(collision_coords_mask) > 0:
                pause_motion.set()
            else:
                pause_motion.clear()

    ## --- FOR TESTING ONLY -- ##
    def advanced_active_lidar_monitoring_with_visualization(self, pause_motion, thread_stop, desired_motor_pos_1, desired_motor_pos_2):

        rr.init(f"Visualize Lidar Brakes_{desired_motor_pos_2}", spawn=True)
        # start_time = time.time()
        while not thread_stop.is_set():
            current_motor_pos_1, current_motor_pos_2 = self.ri.get_motor_positions()

            pulse_diff_motor_1 = desired_motor_pos_1 - current_motor_pos_1
            revs_till_goal = pulse_diff_motor_1 / self.ri.pulse_per_rev
            dist_to_goal = revs_till_goal * self.wheel_circumference

            line_segment = np.array([[0.0, 0.0, dist_to_goal, 0.0]])
            coords, raw_lidar_data = self.read_lidar_updated(wait_for_updated_reading=False)

            # Filter Out Coords Near Robot
            p2p_dists = point_to_points_distance(np.array([0.0, 0.0]), coords[:, :2]).flatten()
            coords = coords[p2p_dists > self.active_distance_threshold]

            dists = point_segment_distance(line_segment, coords[:, :2]) # (1, M)
            dists = dists.flatten()

            collision_coords_mask = dists < self.active_distance_threshold

            if np.sum(collision_coords_mask) > 0:
                pause_motion.set()
            else:
                pause_motion.clear()

            # rr.set_time("time", duration=time.time()-start_time)
            rr.set_time("time", duration=time.time())
            rr.log("lidar points", rr.Points3D(coords))
            rr.log("robot location", rr.Points2D([[0.0, 0.0]], color=[0, 255, 0], radii=(self.wheelbase_length/2)))
        # rr.log_clear()
        rr.disconnect()
    ## --- FOR TESTING ONLY -- ##

    def is_moving(self):
        return np.sum(self.ri.get_motor_velocity()) > 0


    ### --- Motion Monitoring --- ###
    
        # TODO:
    # move_dist -> move_linear (DONE)
    # rotate_rad -> move_angular (DONE)
    # self.r -> move to Robot as self.wheel_radius (DONE)
    # self.L -> move to Robot as self.wheelbase_length (DONE)
    # Swap Prints to Logs
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

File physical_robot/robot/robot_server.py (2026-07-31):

# For GetLatestLidarData 

# 1. Run Redis Lidar Publisher
# 2. Read Latest Lidar Redis Info and Publish it if GetLatestLidarData is called

# For SendMotionCommand
# 1. Robot Will Use RobotInterface to move the robot according to the command
# 2. Robot will send the distance of its wheel motion back to the laptop

from concurrent import futures

import time
import grpc
import physical_robot.generated.robot_data_pb2 as pb2
import physical_robot.generated.robot_data_pb2_grpc as pb2_grpc
import numpy as np
import redis
from physical_robot.robot import Robot

from physical_robot.utils import register_logger
import logging

logger = register_logger(logger_name=__name__, log_filename='robot_server', level=logging.DEBUG, std_err=False)

class RobotServerServicer(pb2_grpc.RobotServer):
    """The server implementation of the RobotServer service."""
    def __init__(self):
        self.robot = Robot(connection='physical')
        # self.redis_client = redis.Redis(host='localhost', port=6379, db=0)

    def _getAndFormatTimestamp(self, key):
        return int(float(self.robot.redis_client.get(key)) * 100000) # TODO: THIS IS BAD


    def GetLatestLidarData(self, request, context):
        """Implements the RPC method."""
        print(f"Server received request: success={request.success}, message='{request.message}'")

        # TODO: Not Required, Request is not an input that matters
        if not request.success:
            # You can set an error status if the request indicates failure
            context.set_code(grpc.StatusCode.INVALID_ARGUMENT)
            context.set_details(request.message)
            return pb2.LidarData() # Return an empty response
        
        lidar_data = np.frombuffer(self.robot.redis_client.get("lidar_data")).reshape(-1, 2)
        timestamp = int(float(self.robot.redis_client.get('time')) * 100000) # TODO: THIS IS BAD

        angles = lidar_data[:, 0]
        dists = lidar_data[:, 1]

        # 1. Create the data to send back
        fake_data = pb2.LidarData(
            angles=angles,
            dists=dists,
            timestamp=timestamp
        )

        # 2. Return the data
        return fake_data
    
    def GetLatestImageData(self, request, context):
        """Implements the RPC method."""

        # Get All RGB Image Data
        rgb_img_bytes = self.robot.redis_client.get('rgb_img')
        rgb_img_shape = self.robot.redis_client.get('rgb_img_shape')
        rgb_img_type = self.robot.redis_client.get('rgb_img_type')

        # Get All Depth Image Data
        depth_img_bytes = self.robot.redis_client.get('stereo_img')
        depth_img_shape = self.robot.redis_client.get('stereo_img_shape')
        depth_img_type = self.robot.redis_client.get('stereo_img_type')

        # Publish Time Images Were Grabbed
        timestamp = self._getAndFormatTimestamp(key='camera_time')

        ## TODO: DO SOME PROCESSING TO THE RAW DATA??

        ## TODO: DO SOME PROCESSING TO THE RAW DATA??

        rgb_img_shape = tuple(np.frombuffer(rgb_img_shape, dtype=np.int64))
        depth_img_shape = tuple(np.frombuffer(depth_img_shape, dtype=np.int64))

        rgb_img = pb2.NumpyArray(
            img_bytes=rgb_img_bytes,
            shape=rgb_img_shape,
            type=rgb_img_type
        )

        depth_img = pb2.NumpyArray(
            img_bytes=depth_img_bytes,
            shape=depth_img_shape,
            type=depth_img_type
        )

        camera_data = pb2.CameraData(
            rgb_img=rgb_img,
            depth_img=depth_img,
            timestamp=timestamp
        )

        return camera_data
    
    def GetLatestIMUData(self, request, context):
        # Publish Accelerometer Data
        accel_x = self.robot.redis_client.get('accel_x')
        accel_y = self.robot.redis_client.get('accel_y')
        accel_z = self.robot.redis_client.get('accel_z')

        # Publish Gyroscope Data
        gyro_x = self.robot.redis_client.get('gyro_x')
        gyro_y = self.robot.redis_client.get('gyro_y')
        gyro_z = self.robot.redis_client.get('gyro_z')

        imu_data = pb2.IMUData(
            accel_x=float(accel_x),
            accel_y=float(accel_y),
            accel_z=float(accel_z),
            gyro_x=float(gyro_x),
            gyro_y=float(gyro_y),
            gyro_z=float(gyro_z)
        )

        return imu_data
    
    def GetLatestPointCloudData(self, request, context):
        # Get Point Cloud Data
        pcl_coords_bytes = self.robot.redis_client.get('pcl_coords')
        pcl_coords_shape = self.robot.redis_client.get('pcl_coords_shape')
        pcl_coords_type = self.robot.redis_client.get('pcl_coords_type')

        pcl_colors_bytes = self.robot.redis_client.get('pcl_colors')
        pcl_colors_shape = self.robot.redis_client.get('pcl_colors_shape')
        pcl_colors_type = self.robot.redis_client.get('pcl_colors_type')

        pcl_coords_shape = tuple(np.frombuffer(pcl_coords_shape, dtype=np.int64))
        pcl_colors_shape = tuple(np.frombuffer(pcl_colors_shape, dtype=np.int64))

        pcl_coords = pb2.NumpyArray(
            img_bytes=pcl_coords_bytes,
            shape=pcl_coords_shape,
            type=pcl_coords_type
        )

        pcl_colors = pb2.NumpyArray(
            img_bytes=pcl_colors_bytes,
            shape=pcl_colors_shape,
            type=pcl_colors_type
        )

        point_cloud_data = pb2.PointCloudData(
            point_cloud_coords=pcl_coords,
            point_cloud_colors=pcl_colors,
            timestamp=self._getAndFormatTimestamp('camera_time')
        )

        return point_cloud_data
    
    def GetLatestOakdLiteData(self, request, context):
        # Get Camera Data
        camera_data = self.GetLatestImageData(request, context)

        # Get IMU Data
        imu_data = self.GetLatestIMUData(request, context)

        # Get Point Cloud Data
        point_cloud_data = self.GetLatestPointCloudData(request, context)

        oakd_lite_data = pb2.OakdLiteData(
            camera_data=camera_data,
            imu_Data=imu_data,
            point_cloud_data=point_cloud_data,
            timestamp=self._getAndFormatTimestamp('camera_time')
        )

        return oakd_lite_data
    
    def SendMotionCommand(self, command, context):
        motion_type = command.motion_type
        dist = command.distance

        m = self.robot.command_motion_trial([motion_type, dist])
        logger.debug(f"Motion Command: ({motion_type}, {dist}) | M: {m}")
        motion_distance = pb2.MotionDistance(
            left_wheel_dist  =   m[0],
            right_wheel_dist =   m[1]
        )
        return motion_distance
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

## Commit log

2025-10-02 Added variable for motor max position
2025-10-03 Fixed encoder numerical issue
2025-10-03 Streaming Lidar Data to Robot
2025-10-04 Map class coordinate frame conversions done
2025-10-05 Lidar Data publishes to local redis server
2025-10-13 Adding ability to simulate lidar readings from map
2025-10-14 Added function template for batch lidar simulations
2025-10-14 Rotation of simulated lidar readings
2025-10-14 Reorganized simulate lidar
2025-10-14 Adding comments describing current map update strategy
2025-10-14 Fixed bug in simulate lidar and started working on batch simulate lidar
2025-10-14 Working on batch lidar readings
2025-10-14 working version of batch simulate lidar without rotation
2025-10-15 Starting Implementation of Particle Filter
2025-10-15 Added particle filter probability calculation
2025-10-15 Added function to animate lidar beams and added more debugging returns in simulate_lidar
2025-10-15 Added temporary fix for simulated lidar beam angles in local frame
2025-10-16 Added more visualization functions and step function for particle filtering
2025-10-16 Particle Filter Running
2025-10-16 Semi-Working Particle Filter
2025-10-17 Removing shared lidar_data variable between processes as this method is no longer used
    [robot.py]
2025-10-18 Fixed particle filter motion function
2025-10-18 Added fixed version of cosmetic robot
    [robot.py]
2025-10-31 Particle filter expands a too small map
2025-10-31 Fixed bug in import
    [robot_server.py]
2025-10-31 Removed deprecated way to read lidar data
2025-10-31 Robot Server sets profile velocity on initialization
2025-10-31 Adding timestamp to lidar data message
2025-10-31 Removed multiprocess lidar data transfer and added shell script to start lidar
2025-10-31 removed unnecessary divison of distance from lidar output
2025-11-01 Adding utils for particle filter testing and drawing robot
2025-11-01 Lidar returns both coords and (angles,dist)
2025-11-01 Particle Filter based localization for robot
2025-11-01 Added function header to convert a kinematic path to motion commands
2025-11-02 Adding shell script to restart lidar if process crashes
2025-11-05 Fixing lidar orientation hack
    [robot.py]
2025-11-06 Templating simulated lidar inside robot
2025-11-06 Filtering Raw Lidar Data
2025-11-07 Templating reactive lidar stopping
2025-11-07 Outlining active lidar monitoring in robot
2025-11-08 Added new method to try for pausing the motors
2025-11-08 Adding advanced robot active lidar monitoring
2025-11-08 Added mutex locks to interfacing with motors
2025-11-08 Adding set motor positions function
2025-11-09 Robot server uses robot object to get lidar readings
2025-11-09 Fixing bug with robot obj migration
    [robot_server.py]
2025-11-09 Adding visualization to monitoring thread
2025-11-15 Adding file to handle publishing camera data
2025-11-15 Adding archive camera reader
2025-11-15 Camera publisher working
2025-11-15 Fixing key for time in camera publisher
2025-11-15 Templating new sensor functions
2025-11-15 Adding camera images to proto structure
2025-11-15 Adding camera data exporter to robot server
2025-11-15 Test file for particle filter
2025-11-15 Fixing typos in server implementation
    [robot_server.py]
2025-11-15 Added read rgb cameras function, fixed a bug with output of command_motion_and_predict_state, and fixed variable name issue
    [robot.py]
2025-11-16 Adding imu data to camera publishing logic
2025-11-16 Added IMUData messages to proto and MonitoringState messages
2025-11-16 Adding imu data communication interface
2025-11-16 Returning imu data from read_imu function
2025-11-17 Adding timeout to get imu rpc call
2025-11-19 Shell script to run start camera
2025-11-19 Adding script to run all sensors
2025-12-04 Added timer function decorator to utils
2025-12-06 Fixing bug where physical robot would return none for rgb camera read function
    [robot.py]
2025-12-06 Adding script to generate point cloud on camera compute
2025-12-06 Fixing formatting issue with numpy array shape for proto buffers
    [robot_server.py]
2025-12-06 Fixed conversion from bytes to rgb and depth images
    [robot.py]
2026-01-08 Adding comment to fix issue with particle filter after map design is done
2026-01-08 Adding label and filtering pc function
2026-01-09 Add function to print item ids for room and object
2026-01-09 Fixing particle filter implementation to use updated map inference
2026-01-09 Adding Log Statements instead of print statements
2026-01-12 Adding target state print statement
2026-01-13 Fixing camera command
2026-01-13 Adding get position and velocity functions to rpc schema
2026-01-14 Fixing bug with robot server using the position proto for veloticies
    [robot_server.py]
2026-01-16 Adding functionality to robot to read motor position
2026-01-17 Adding autoretry functionality to read lidar if the number of points returned is too small
    [robot.py]
2026-01-24 Frontier candidates are filtered by how close they are to obstacle points
2026-02-03 Adding particle filter icp refinement
2026-02-06 Adding warning print message to gemma vlm client
2026-03-23 Adding files to test sensors physically attached to the computer
2026-03-23 Adding file to test physical lidar sensor
2026-03-23 Adding todo in imu testing file
2026-04-17 Adding robot cad designs
    [430T Motor Mounts.stl, 8 AA Battery Holder Horizontal.stl, Camera Mounting Bracket.stl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]
2026-04-21 Adding the ability for map builder to track the trajectory of a robot
2026-05-03 Adding file to debug lidar angles
2026-05-03 Adding file to debug simulated lidar
2026-05-03 Adding visualizations of robot sensor test files
2026-05-07 Moving icp and particle filter to algorithms directory
2026-05-07 Moving robot motor interface code
2026-05-07 Moving sensor visualizations to monitoring directory
2026-05-07 Moving sensors to sensors subdirectory
2026-05-08 Moving sensors to hardware directory
2026-05-08 Fixing particle filter imports
2026-05-08 Fixing imports in robot server
    [robot_server.py]
2026-05-08 Removing particle filter test file from wrong location
2026-05-09 Adding very basic voxel pc filtering
2026-05-14 Commenting out point cloud filtering
2026-06-17 Updating Readme with usable instructions such as build list and part print list
2026-06-18 Linking cad files in readme
2026-06-18 Working on adding sensor descriptions
2026-06-18 Updating size of sensor images
2026-06-18 Adding motors to readme
2026-06-20 Updating commandds to run sensors in shell scripts
2026-07-31 Fixing some logging statements
    [robot_server.py]
2026-08-05 Adding test case
2026-08-15 Formating viz camera file
2026-08-23 Converting vlm tests to unittest framework
2026-08-24 Cleaning code in particle filter
2026-08-24 Fixed camera monitoring to work with client
2026-08-25 Fixing miss calculation in motor differentials when wraparound error occurs
    [robot.py]
2026-08-25 Fixing motor interfact formatting
    [robot_motor_interface.py]
2026-08-28 Adding segmentation filtering
2026-08-28 Removing print statement from filtering function
2026-09-26 Working on sensor health checks
2026-09-28 Adding frame time calculation
